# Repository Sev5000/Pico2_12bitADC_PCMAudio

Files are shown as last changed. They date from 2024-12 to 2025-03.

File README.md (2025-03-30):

# Pico2_12bitADC_PCMAudio
This is a PCB to neatly package a Raspberry Pi Pico 2, AD9226 ADC PCB and a PCM1802 audio board for capture with hsdaoh.
Specifically designed to still be usefull without smds (no head switch input then). Through-hole only works just fine.
For use with https://github.com/steve-m/hsdaoh-rp2350/tree/pcm1802

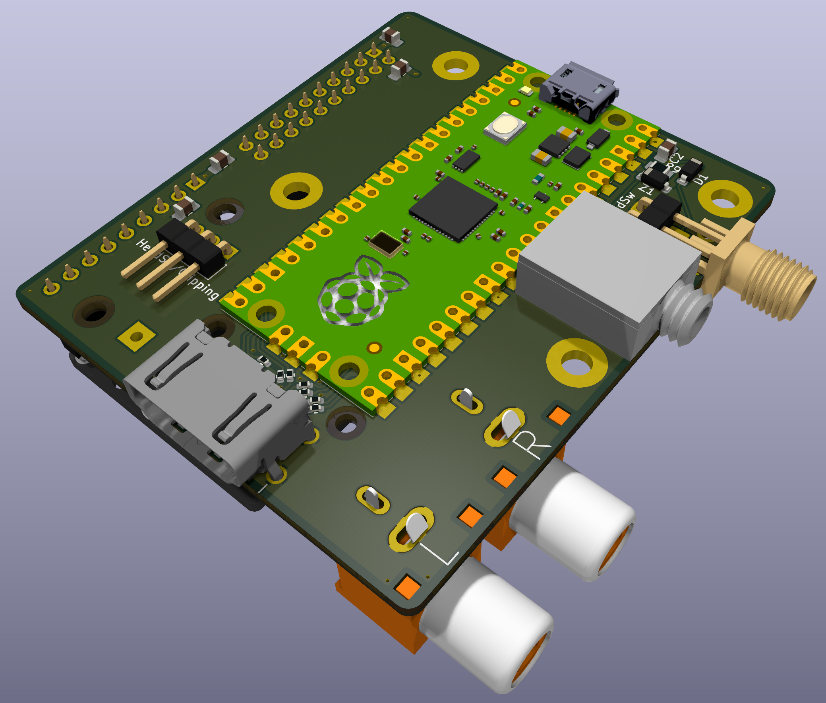
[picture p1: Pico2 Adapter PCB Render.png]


Features:
- The Pico 2 can be socketed with and without a DVI sock
- Mounting holes for the AD9226 pcb, PCM1802 and a socketed Pi Pico 2 with DVI sock (original and adafruit verfied)
- Audio input with either chinch or 3.5mm jack
- Jumper to choose between head switch input and clipping bit of the AD9226
- Protected head switch input has footprints for jst, as well as edge and horizontal SMA/SMB

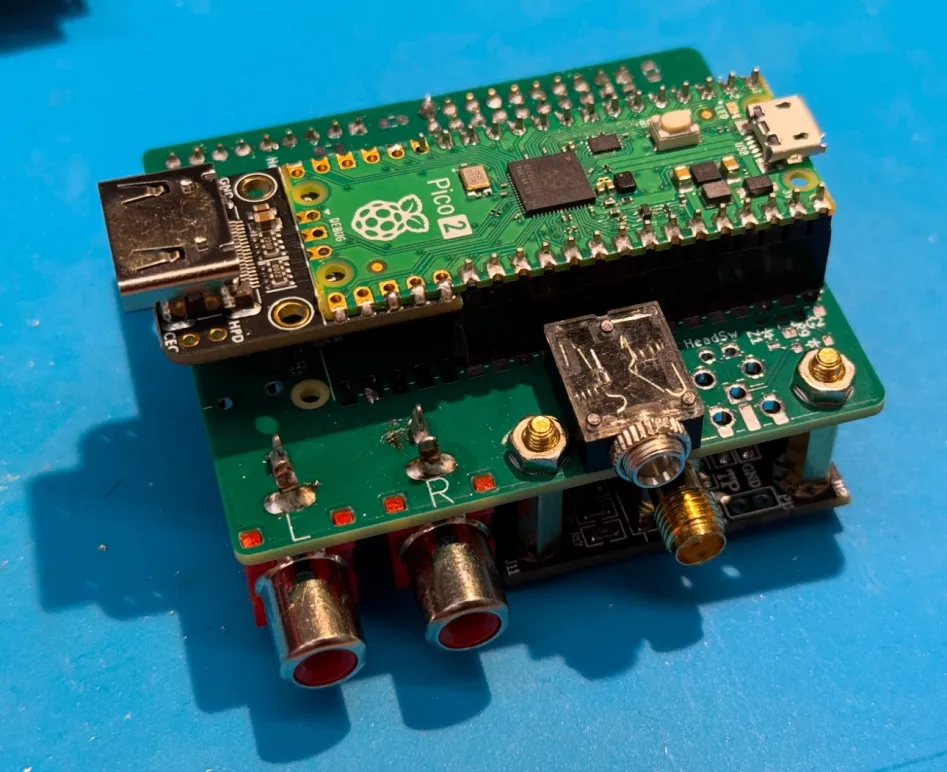
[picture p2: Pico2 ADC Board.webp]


Bill of material: 
- 1x This PCB (Send the Gerber .zip to JLC, PCBWay, ..)
- 1x Raspberry Pi Pico 2
- 1x AD9226: https://aliexpress.com/item/1005003038271519.html
- 1x PCM1802: https://aliexpress.com/item/1005006412873984.html
- 2x RCA-105 or RCA-106: https://aliexpress.com/item/1005006152724809.html
- 1x PJ-324M 5P: https://aliexpress.com/item/1005006146950431.html
- 1x 3pin 2.54mm pin header horizontal for the headswitch/overflow selection jumper
- 1x 9pin 2.54mm pin-socket header 
- 1x 2x10pin 2.54mm pin-socket header
- 1x 3pin 2.54mm pin header (remove the center pin for connecting R/L of the PCM1802)
- 1x 3pin 2.54mm pin-socket header (remove the center pin for connecting R/L of the PCM1802)

No SMD variant:
- 1x DVI-Sock: https://github.com/Wren6991/Pico-DVI-Sock for a flush fit with the pcb edge, otherwise the adafruit DVI sock works fine too
- 2x 15pin 2.54mm pin-socket header

SMD Variant:
- 1× Stewart SS-53000-001 connector (See https://github.com/Wren6991/Pico-DVI-Sock BOM for details)
- 8× 0402 270 ohm resistors
- 5x 0805 100nF ceramic capacitors
- 2x 20pin 2.54mm pin-socket header (For socketed Pi Pico 2 only)

For head switch input:
- 1x SOD123 3.3V zener diode
- 1x SOD123 standard diode
- 1x 0805 1k resistor
- 1x edge SMA/SMB or horizontal SMA/SMB and/or 2pin header

Notes:
The PCM1802 board needs MODE0 (MODE1 only with previous HSDAOH releases) bridged *and* connected to 3.3V with a wire (Those boards have a design error):
NOTE: Picture shows the configuration for the older firmware, now only MODE0 needs to be bridged and connected to 3.3V

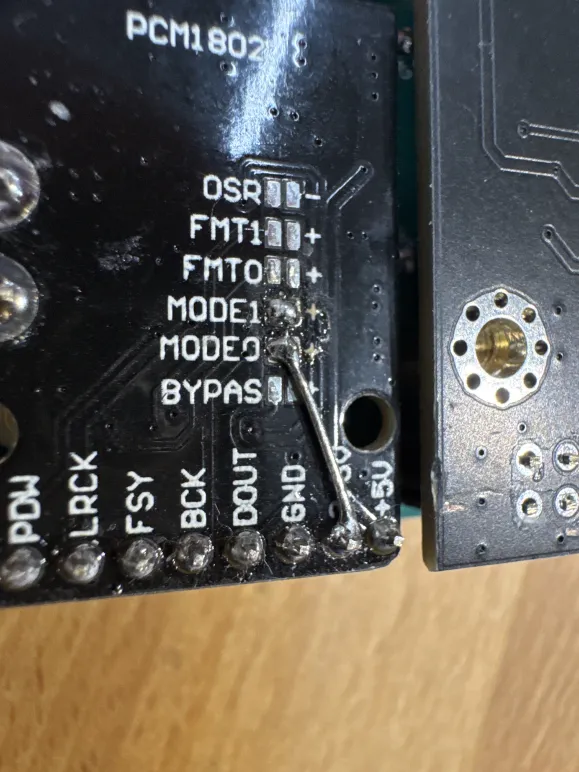
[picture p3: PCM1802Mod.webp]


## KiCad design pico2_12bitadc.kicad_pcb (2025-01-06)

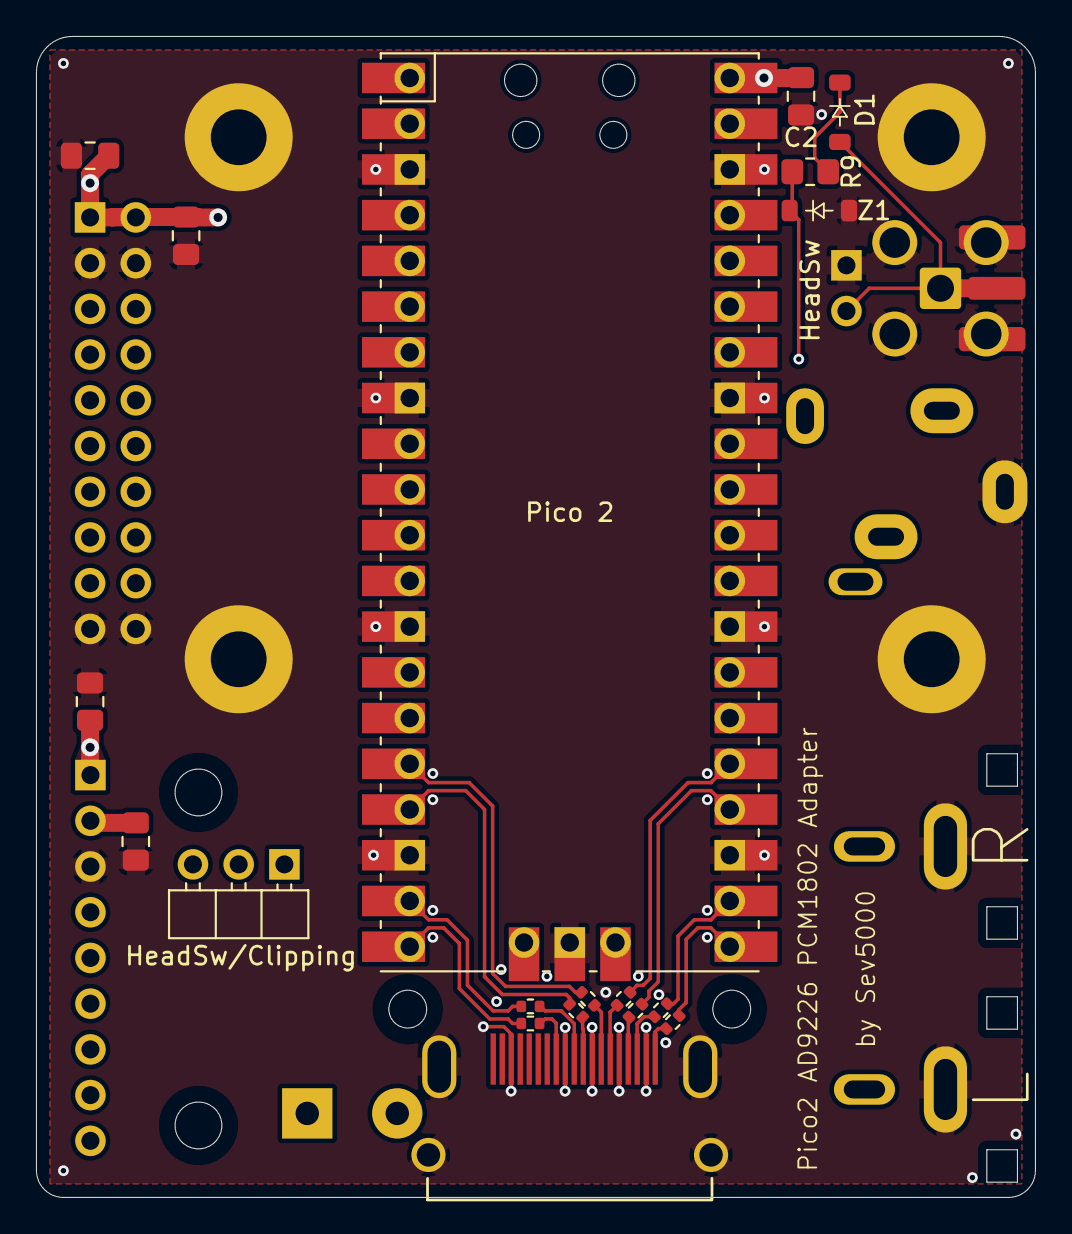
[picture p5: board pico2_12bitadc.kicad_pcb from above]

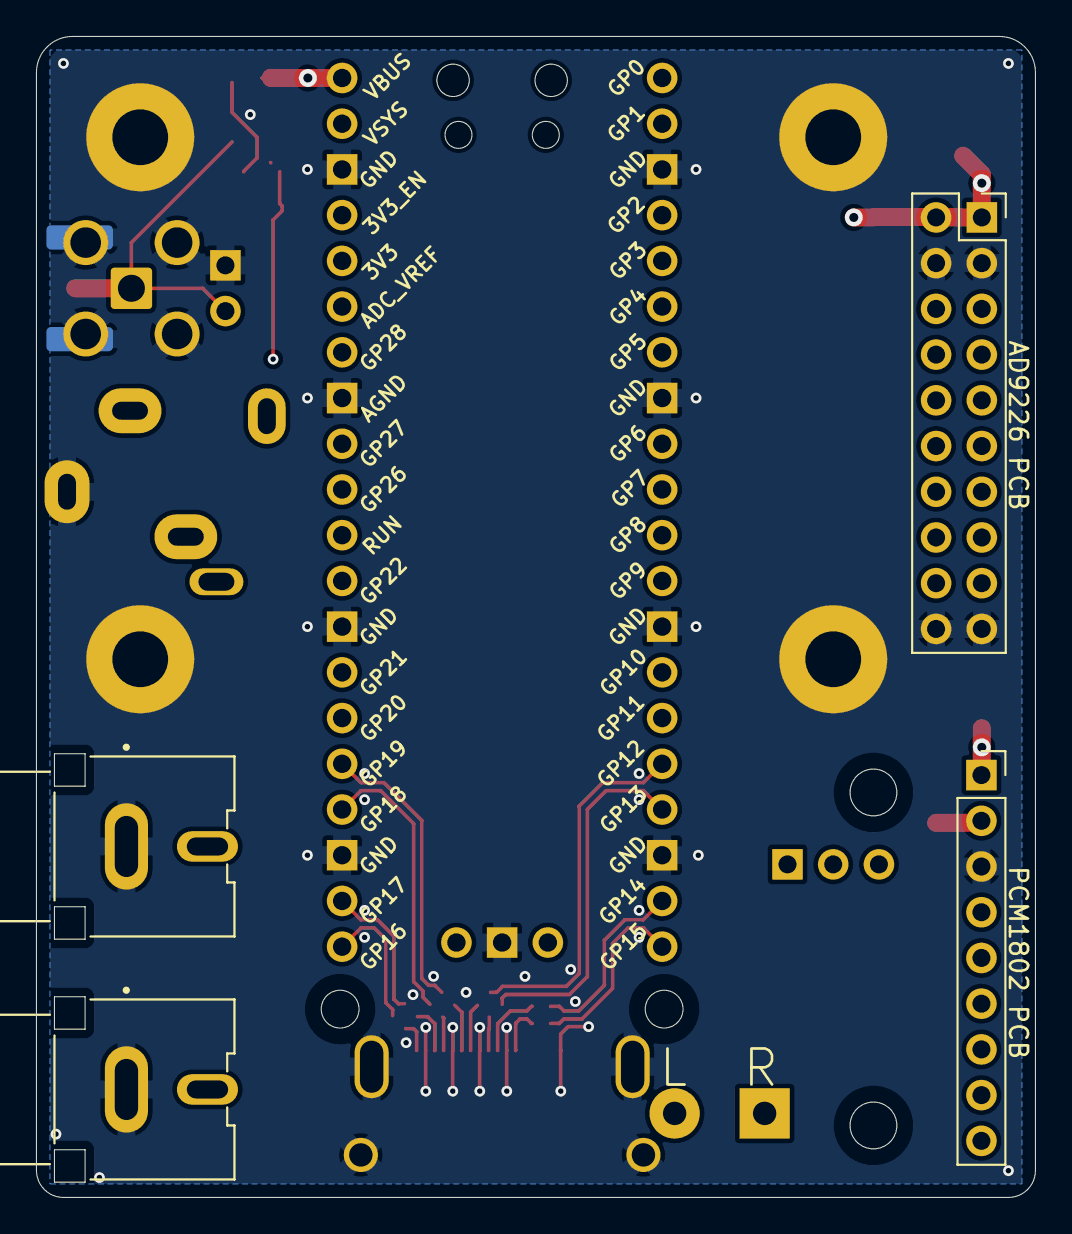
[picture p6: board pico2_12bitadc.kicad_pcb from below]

Board: 4 copper layers, 55.5 x 64.5 mm, 28 parts (4 on the bottom side), 43 nets.

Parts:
C1, C2, C3, C4, C5: 100nF; C_0805_2012Metric_Pad1.18x1.45mm_HandSolder
D1: D; D_SOD-123
J1: NOT_HDMI_A; HDMI-SS-53000
J2: PCM1802 PCB; PinSocket_1x09_P2.54mm_Vertical
J3: AD9226 PCB; PinSocket_2x10_P2.54mm_Vertical
J4: L R; TerminalBlock_MaiXu_MX126-5.0-02P_1x02_P5.00mm
J5: L; CUI_RCJ-047
J6: HeadSw/Clipping; PinHeader_1x03_P2.54mm_Horizontal
J7: R; CUI_RCJ-047
J8: AudioJack2_Ground_Switch; Jack_3.5mm_CUI_SJ1-3515N_Horizontal
J9: HeadSw; PinHeader_1x02_P2.54mm_Horizontal
J10: SMA90; SMA_Amphenol_901-143_Horizontal
J11: SMAEdge; SMA_Samtec_SMA-J-P-H-ST-EM1_EdgeMount
Pico 2: Pico; RPi_Pico_SMD_TH
R1, R2, R3, R4, R5, R6, R7, R8: 270; R_0402_1005Metric
R9: 1k; R_0805_2012Metric_Pad1.20x1.40mm_HandSolder
Z1: D_Zener3.3V; D_SOD-123

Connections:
+5V: C1.1, C2.1, C4.1, C5.1, J1.18 (+5V), J2.5V (Pin_1), J3.5V (Pin_1), Pico 2.40 (VBUS)
/CK+: J1.10 (CK+), R7.2
/CK-: J1.12 (CK-), R8.2
/D0+: J1.7 (D0+), R5.2
/D0-: J1.9 (D0-), R6.2
/D1+: J1.4 (D1+), R3.2
/D1-: J1.6 (D1-), R4.2
/D2+: J1.1 (D2+), R1.2
/D2-: J1.3 (D2-), R2.2
/PICO_CK+: Pico 2.19 (GPIO14), R7.1
/PICO_CK-: Pico 2.20 (GPIO15), R8.1
/PICO_D0+: Pico 2.16 (GPIO12), R5.1
/PICO_D0-: Pico 2.17 (GPIO13), R6.1
/PICO_D1+: Pico 2.24 (GPIO18), R3.1
/PICO_D1-: Pico 2.25 (GPIO19), R4.1
/PICO_D2+: Pico 2.21 (GPIO16), R1.1
/PICO_D2-: Pico 2.22 (GPIO17), R2.1
GND: C1.2, C2.2, C3.2, C4.2, C5.2, J1.2 (D2S), J1.5 (D1S), J1.8 (D0S), J1.11 (CKS), J1.17 (GND), J1.SH, J2.GND (Pin_3), J3.GND (Pin_4), J5.1 (In), J7.1 (In), J8.S, J9.1, J10.2 (Ext), J11.2 (Ext), Pico 2.3 (GND), Pico 2.8 (GND), Pico 2.13 (GND), Pico 2.18 (GND), Pico 2.23 (GND), Pico 2.28 (GND), Pico 2.33 (AGND), Pico 2.38 (GND), Pico 2.42 (GND), Z1.2 (A)
unnamed: D1.2 (A), J9.2, J10.1 (In), J11.1 (In)
unnamed: D1.1 (K), R9.1
unnamed: J6.1, R9.2, Z1.1 (K)
unnamed: C3.1, J2.3.3V (Pin_2), J2.PDW (Pin_8)
unnamed: J2.DOUT (Pin_4), Pico 2.29 (GPIO22)
unnamed: J2.BCK (Pin_5), Pico 2.31 (GPIO26_ADC0)
unnamed: J2.LRCK (Pin_7), Pico 2.32 (GPIO27_ADC1)
unnamed: J2.SCK (Pin_9), Pico 2.27 (GPIO21)
unnamed: J3.CLK (Pin_5), Pico 2.26 (GPIO20)
unnamed: J3.D0 (Pin_6), Pico 2.1 (GPIO0)
unnamed: J3.D1 (Pin_7), Pico 2.2 (GPIO1)
unnamed: J3.D2 (Pin_8), Pico 2.4 (GPIO2)
unnamed: J3.D3 (Pin_9), Pico 2.5 (GPIO3)
unnamed: J3.D4 (Pin_10), Pico 2.6 (GPIO4)
unnamed: J3.D5 (Pin_11), Pico 2.7 (GPIO5)
unnamed: J3.D6 (Pin_12), Pico 2.9 (GPIO6)
unnamed: J3.D7 (Pin_13), Pico 2.10 (GPIO7)
unnamed: J3.D8 (Pin_14), Pico 2.11 (GPIO8)
unnamed: J3.D9 (Pin_15), Pico 2.12 (GPIO9)
unnamed: J3.D10 (Pin_16), Pico 2.14 (GPIO10)
unnamed: J3.D11 (Pin_17), Pico 2.15 (GPIO11)
unnamed: J3.OTR (Pin_18), J6.3
unnamed: J4.1, J7.2 (Ext), J8.R
unnamed: J4.2, J5.2 (Ext), J8.T
unnamed: J6.2, Pico 2.34 (GPIO28_ADC2)

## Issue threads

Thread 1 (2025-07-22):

Add license information

vazhnov, 2025-07-22:
Hello!

I found this amazing project from https://github.com/steve-m/hsdaoh-rp2350

Could you please add information about the license of this repository — is it allowed to copy, change and use the documentation and PCB hardware files in any purpose?
It would be great to see any popular open source license.

Sev5000, 2025-08-05:
Hi, sorry for the late response. I haven’t really thought it through. I’d say non commercial use is fine.

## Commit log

2025-01-04 Update pico2_12bitadc.kicad_pcb
    Fixed hole spacing of the ad9226 pcb footprint
    [pico2_12bitadc.kicad_pcb]
2025-01-04 Update pico2_12bitadc.kicad_pcb
    Fixed trace near new hole position
    [pico2_12bitadc.kicad_pcb]
2025-01-04 Update pico2_12bitadc.kicad_pcb
    Added Name
    [pico2_12bitadc.kicad_pcb]
2025-01-04 Update pico2_12bitadc.kicad_pcb
    Minor silkscreen adjustments
    [pico2_12bitadc.kicad_pcb]
2025-01-06 Update pico2_12bitadc.kicad_pcb
    Increased pad length and through hole size of the hdmi connector for better compatability with other connector models
    [pico2_12bitadc.kicad_pcb]
2025-02-03 Add Gerber Files
